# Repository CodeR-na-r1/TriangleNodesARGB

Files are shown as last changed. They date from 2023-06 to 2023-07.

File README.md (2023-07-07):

# Проект по летней практике 2023

## О проекте

Этот проект - моя попытка сделать многофункциональный модульный светильник с ноля за 20 дней. Задач было много: от разработки концепта и корпуса для светильника до написания кода на с++ arduino для реализации функционала. Написание кода оказалось не простой задачей, так как заставить микроконтроллеры коммуницировать между собой с условием, что в run-time может меняться конфигурация системы, довольно сложно.

Результаты можно посмотреть в этом видео -> https://youtu.be/zxDmPbXJ-Gc

## Как запустить проект

Установаить поддержку для esp8266 в Arduino IDE, добавить нужные библиотеки (инструкция ниже) и загрузить прошивку на МК.

## Модули, библиотеки (список, способ установки)

+ Wi-Fi: Работа с подключением к сетям Wi-Fi, а также создание собственной точки доступа Wi-Fi (by default)
+ FastLED: Удобная работа с адресной светодиодной лентой (FastLED by Daniel Garcia)
+ Ticker: Работа с прерываниями по таймеру (by default)
+ ESPAsyncWebSrv: Запуск веб-сервера на микроконтроллере (ESPAsyncWebSrv by dvarrel) (https://github.com/dvarrel/ESPAsyncWebSrv)

Библиотеки либо уже установлены в Arduino IDE (те, что с меткой *by default*), либо устанавливаются через менеджер библиотек

## Основные компоненты:

1. Плата мк esp8266
2. Адресная светодиодная лента, плотность не менее 60 светодиодов на метр, длина 12-24 светодиода
3. Макетная плата для размещения компонентов (при помощи пайки)

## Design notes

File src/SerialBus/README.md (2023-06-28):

Библиотека для объединения микроконтроллеров в единую сеть с общей шиной при помощи интерфейса UART (SoftwareSerial).

В конструкторе необходимо настроить нужный размер буффера, так как библиотека пока что не защищена от его переполнения.

Преимущества:
+ Возможность динамической адресации (по сравнению с i2c или spi). Во время выполнения, мк имеет возможность поменять свой адрес.
    > Каждому отправляемому сообщению можно назначить адрес, либо отправить сообщение для всех (широковещательная рассылка)
+ Высокая скорость передачи данных по сравнению с другими топологиями сети, например кольцевая шина
+ Высокая надежность
    > Встроенная проверка crc при получении сообщения, а также возможность отправлять сообщения, на которые получатель обязательно должен ответить

Ограничения работы:
+ В системе может быть только один мастер. (Но можно адаптировать под нескольких)
+ Все платы slave слышат только мастера, и общаются только с мастером. Они не видят друг друга.
+ Мастер слышит всех и вещает всем.
+ Нельзя допускать, чтобы одновременно более 1 slave говорили что-то мастеру. (это должно контролироваться мастером, например, выдавать квант каждому slave поочереди ИЛИ slave имеет право голоса только если его спросили)

Схема соединения следующая:

> Fake - любой незанятый цифровой пин. Используется библиотекой для работы с Serial.

Гибкая настройка буффера:
+ Задать размер __максимального размера сообщения__ можно прямо в конструкторе класса библиотеки (SerialBusMaster или SerialBusSlave). Имя параметра - _bufferSize_
+ Задать __размер очереди поступаемых сообщений__ - это настраивается через определение директивы препроцессора для библиотеки SoftwareSerial. (Подробнее тут: https://forum.arduino.cc/t/increasing-arduino-serial-buffer-size/322151/19)
    > Вкратце: перед подключением заголовочных файлов SerialBus и SoftwareSerial определить нужную директиву из этих двух (либо две сразу):
    _#define SERIAL_TX_BUFFER_SIZE 128_
    _#define SERIAL_RX_BUFFER_SIZE 128_

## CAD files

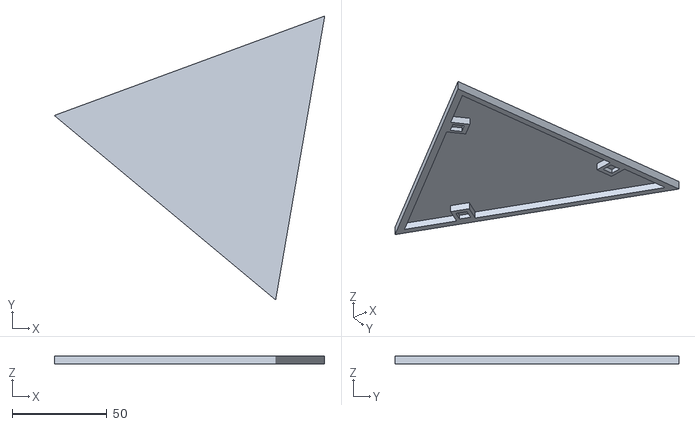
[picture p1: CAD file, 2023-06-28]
3D objects/Node/TreeNode_cap.stl
143.1 x 150.2 x 4.40

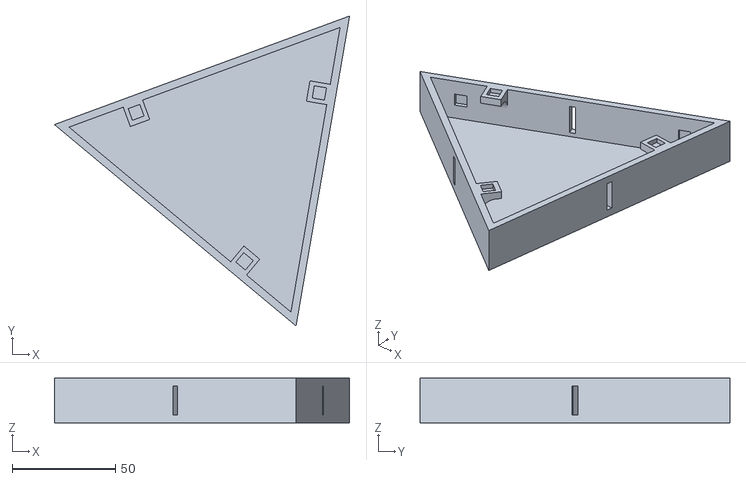
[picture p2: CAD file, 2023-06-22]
3D objects/Node/TreeNode_base.stl
143.1 x 150.2 x 21.6

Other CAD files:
3D objects/Node/TreeNode v1 aka 1.1.f3d
3D objects/Node/TreeNode v1 aka 1.2.f3d
3D objects/Node/TreeNode v1 aka 1.f3d

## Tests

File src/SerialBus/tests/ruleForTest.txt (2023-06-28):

Алгоритм проведения теста:
1. Прошить платы (master + slave). Дождаться.
2. Отключить master
3. Перезагрузить slave
4. Открыть монитор порта для нужных плат (у мастера больше всего инфы)
5. Подключить master

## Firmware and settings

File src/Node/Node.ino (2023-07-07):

#include <Ticker.h>  //Ticker Library

// #define DEBUG_

#include "SerialBusSlave.h"
#include "MSG_TYPES.h"
#include "ARGB_MODES.h"
#include "LedManager.h"

#define MSG_TIME_WAIT 300
#define MSG_SEND_INTERVAL 200
const uint32_t MULTIPLIER_TIMEOUT_PING = 5000;
uint32_t TIMEOUT_PING = MULTIPLIER_TIMEOUT_PING * 1;

#define RX_PIN 4     // D2
#define TX_PIN 0     // D3
#define FAKE_PIN 16  // D0

#define WDP_PIN 2    // D4
#define WDC0_PIN 12  // D6 (right neigbour)
#define WDC1_PIN 14  // D5 (down neigbour)

#define LED_PIN 5  // D1
#define LED_NUM 12

SerialBusSlave bus = SerialBusSlave(RX_PIN, TX_PIN, FAKE_PIN, BROADCAST_ADDR, 100);  // RX 2 TX 3 Fake 0 addr 0 bufSz 100
char* buffer = new char[100];

// void (*animationFunction)() = nullptr;

Ticker ticker;

bool addrSuccess = false;
auto timerPingResponse = millis();
auto timerLastPing = millis();

ColorRGB color = ColorRGB(59, 26, 93);
ColorRGB colorBackground = ColorRGB(0, 0, 0);
ARGB_MODES mode = ARGB_MODES::STATIC_COLOR;
uint8_t timeDelayAnimation = 60;

void setup() {
  Serial.begin(9600);
  Serial.println("ESP started");

  LED_MANAGER::setUp();

  pinMode(WDP_PIN, INPUT_PULLUP);
  pinMode(WDC0_PIN, OUTPUT);
  pinMode(WDC1_PIN, OUTPUT);

  digitalWrite(WDC0_PIN, HIGH);
  digitalWrite(WDC1_PIN, HIGH);

  // SET LOADING STATIC COLOR
  LED_MANAGER::setBrightness(80);
  color = ColorRGB(255, 255, 255);
  reInitAnimation();

  while (true) {  // дальше не идем пока не получим адрес

    if (isPing()) {  // если нас опрашивают

      if (getAddr()) {  // пробуем получить адрес

        addrSuccess = true;
        // TODO SET RAINBOW ANIMATION
        break;
      }
    } else {
      bus.clearBuffer();  // пока мы ждем,
                          // возможно сейчас присвают адрес другим slave при помощи широковещательного сообщения - нам это не нужно,
                          // поэтому чистим буфер
    }
  }

  Serial.println("ESP ready");
  Serial.print("Addr =");
  Serial.println(bus.getAddress());

  LED_MANAGER::setBrightness(255);
  mode = ARGB_MODES::ANIMATION;
  color = ColorRGB(23, 8, 59);
  LED_MANAGER::initLoadAnimation(color, colorBackground, 0, 3, 1);
  timeDelayAnimation = 240;
  reInitAnimation();

  timerPingResponse = millis();
  timerLastPing = millis();
}

void loop() {

  if (bus.available()) {

    char cmd = bus.getData()[0];

    switch (cmd) {

      case static_cast<char>(MSG_TYPES::PING):
        buffer[0] = static_cast<char>(MSG_TYPES::PONG);
        bus.send(1, buffer, 1);
        break;

      case static_cast<char>(MSG_TYPES::SET_TIMEOUT_PING):
        TIMEOUT_PING = MULTIPLIER_TIMEOUT_PING * bus.getData()[1];
        timerLastPing = millis();
        break;

      case static_cast<char>(MSG_TYPES::SET_WD_0):
        digitalWrite(WDC0_PIN, LOW);
        break;

      case static_cast<char>(MSG_TYPES::SET_WD_1):
        digitalWrite(WDC1_PIN, LOW);
        break;

      case static_cast<char>(MSG_TYPES::RESET_WDs):
        digitalWrite(WDC0_PIN, HIGH);
        digitalWrite(WDC1_PIN, HIGH);
        break;

      case static_cast<char>(MSG_TYPES::BRIGHTNESS):
        LED_MANAGER::setBrightness(bus.getData()[1]);
        reInitAnimation();
        break;

      case static_cast<char>(MSG_TYPES::DELAY):
        timeDelayAnimation = bus.getData()[1];
        reInitAnimation();
        break;

      case static_cast<char>(MSG_TYPES::LED_COLOR_INFO):
        color = ColorRGB(bus.getData()[1], bus.getData()[2], bus.getData()[3]);
        reInitAnimation();
        break;

      case static_cast<char>(MSG_TYPES::LED_MODE_INFO):
        mode = static_cast<ARGB_MODES>(bus.getData()[1]);
        reInitAnimation();
        break;
    }

    Serial.print("getRXaddress=");
    Serial.println(bus.getRXaddress());
    Serial.print("getAddress=");
    Serial.println(bus.getAddress());
    if (bus.getRXaddress() == bus.getAddress()) {
      Serial.print("update timerLastPing");
      timerLastPing = millis();
    }
  }

  if ((millis() - timerLastPing > TIMEOUT_PING) && addrSuccess) {

    addrSuccess = false;
    Serial.print("Addr lost!");
    // TODO SET RECONECT ANIMATION
    LED_MANAGER::initLoadAnimation(ColorRGB(255, 0, 0), ColorRGB(0, 0, 0), 0, 3, 1);
    mode = ARGB_MODES::ANIMATION;
    timeDelayAnimation = 80;
    reInitAnimation();
  }

  if (isPing()) {

    if (addrSuccess) {

      if (millis() - timerPingResponse > MSG_SEND_INTERVAL) {

        buffer[0] = static_cast<char>(MSG_TYPES::OK);
        bus.send(1, buffer, 1);
        timerPingResponse = millis();
      }
    } else {

      if (millis() - timerPingResponse > MSG_SEND_INTERVAL) {

        if (getAddr()) {  // пробуем получить адрес

          addrSuccess = true;
          Serial.print("Addr restored!");
          // SET DEFAULT ANIMATION
          mode = ARGB_MODES::ANIMATION;
          LED_MANAGER::initLoadAnimation(color, colorBackground, 0, 3, 1);
          timeDelayAnimation = 240;
          reInitAnimation();
        }
        timerPingResponse = millis();
      }
    }
  }
}

bool waitMessage() {
  auto timer = millis();

  while (millis() - timer < MSG_TIME_WAIT) {
    if (bus.available()) {
      break;
    }
  }

  return bus.available();
}

bool isPing() {

  if (!digitalRead(WDP_PIN)) {  // если нас опрашивают

    // Serial.println("WDP is active");

    auto timer = millis();
    bool flagSuccessful = false;

    while (!digitalRead(WDP_PIN)) {  // проверяем некоторое время, что сигнал не пропал (защита от помех)

      if (millis() - timer > 20) {

        flagSuccessful = true;
        break;
      }
      delay(1);
    }

    return flagSuccessful;
  }

  return false;
}

bool getAddr() {

  Serial.println("Try get addr -> send broadcast");

  bus.clearBuffer();

  buffer[0] = static_cast<char>(MSG_TYPES::GET_ADDR);  // говорим что нам нужен адрес
  bus.send(1, buffer, 1);

  if (!waitMessage()) {  // не дождались ответа
    Serial.println("!ERROR Try get addr -> no msg");
    return false;
  }

  if (bus.getData()[0] != static_cast<char>(MSG_TYPES::SET_ADDR)) {  // не тот тип ответа
    Serial.println("!ERROR Try get addr -> miss type msg (!= ::SET_ADDR)");
    return false;
  }

  uint8_t newAddr = bus.getData()[1];  // если до сюда дошли, значит мы получили адрес
  bus.changeAddress(newAddr);          // меняем свой адрес

  buffer[0] = static_cast<char>(MSG_TYPES::PONG);  // отмечаемся
  bus.send(1, buffer, 1);

  return true;
}

void reInitAnimation() {

  ticker.detach();

  if (mode == ARGB_MODES::STATIC_COLOR) {

    LED_MANAGER::showColor(color);

  } else if (mode == ARGB_MODES::STATIC_COLOR_ANIM) {

    LED_MANAGER::ledFunction = LED_MANAGER::tickStaticColor;

    // if (timeDelayAnimation < 100) { timeDelayAnimation = 270; }  // remove it if user setting delay in web-interface
    ticker.attach_ms(timeDelayAnimation, interruptFunction);

  } else if (mode == ARGB_MODES::ANIMATION) {

    LED_MANAGER::ledFunction = LED_MANAGER::tickAnimation;
    ticker.attach_ms(timeDelayAnimation, interruptFunction);

  } else if (mode == ARGB_MODES::RAINBOW_ANIM) {

    LED_MANAGER::ledFunction = LED_MANAGER::rainbow_fade;
    // timeDelayAnimation = 20;
    ticker.attach_ms(timeDelayAnimation, interruptFunction);

  } else if (mode == ARGB_MODES::COLOR_BOUNCE_FADE) {

    LED_MANAGER::ledFunction = LED_MANAGER::color_bounceFADE;
    // timeDelayAnimation = 20;
    ticker.attach_ms(timeDelayAnimation, interruptFunction);
  }
}

IRAM_ATTR void interruptFunction() {

  LED_MANAGER::ledFunction();
}

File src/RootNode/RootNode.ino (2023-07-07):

#include <SoftwareSerial.h>

// #define DEBUG_

#include "SerialBusMaster.h"
#include "MSG_TYPES.h"
#include "ServerModule.h"
#include "ARGB_MODES.h"

#define MSG_TIME_WAIT 250
#define PING_PONG_FREQUENCY 850

#define RX_PIN 4  // D2
#define TX_PIN 0  // D3

SoftwareSerial mySerial(RX_PIN, TX_PIN);  // RX, TX (2, 3)

#define WD_PIN 5  // D1

SerialBusMaster bus(&mySerial, 1, 100);
char* buffer = nullptr;

std::vector<uint8_t> nodes;
uint8_t freeAddr = 2;

auto timerPingPong = millis();

/* address strip parameters */

char brightness = 255;
char ledDelay = 240;
char mode = static_cast<char>(ARGB_MODES::ANIMATION);
char rColor = 23;
char gColor = 8;
char bColor = 59;

char* queueBuffer = new char[20];
uint8_t queueSize = 0;
bool isQueueData = false;

void setup() {
  Serial.begin(9600);
  mySerial.begin(9600);
  Serial.println("ESP started");

  if (WIFI_AP_NAMESPACE::start() == 0) {
    Serial.println("WIFI AP created");
  } else {
    Serial.println("Wifi AP created error!");
  }

  int ret = SERVER_NAMESPACE::start();

  if (ret == 0) {
    Serial.println("Server started;");

    SERVER_NAMESPACE::setuserCahngeColorCallback(serverChangeColorCallback);
    SERVER_NAMESPACE::setuserCahngeBrightnessCallback(serverChangeBrightnessCallback);
    SERVER_NAMESPACE::setuserCahngeDelayCallback(serverChangeDelayCallback);
    SERVER_NAMESPACE::setuserCahngeModeCallback(serverChangeModeCallback);
    Serial.println("setUserCallback is set");
  } else {
    Serial.print("Server started, with error, retValue -> ");
    Serial.println(ret);
  }

  buffer = new char[100];

  nodes.reserve(10);

  pinMode(WD_PIN, OUTPUT);

  digitalWrite(WD_PIN, LOW);

  while (true) {  // дальше не идем пока не подключимся к 1 ноде

    if (waitMessage()) {  // получили ответ от ноды

      Serial.println("msg get");
      if (assignAddress()) {  // попытка дать адрес

        digitalWrite(WD_PIN, HIGH);
        break;  // успешно - выходим
      }
    }
  }
  Serial.println("first node find");

  timerPingPong = millis();
}

uint8_t nodeIterator = 0;
bool isSecondNeigbour = false;

void loop() {

  if (millis() - timerPingPong > PING_PONG_FREQUENCY) {

    bus.clearBuffer();

    buffer[0] = static_cast<char>(MSG_TYPES::PING);
    bus.send(nodes[nodeIterator], buffer, 1);

    if (waitMessage()) {

      if (bus.getData()[0] == static_cast<char>(MSG_TYPES::PONG)) {

        buffer[0] = static_cast<char>(isSecondNeigbour == false ? MSG_TYPES::SET_WD_0 : MSG_TYPES::SET_WD_1);
        bus.send(nodes[nodeIterator], buffer, 1);

        if (waitMessage()) {  // получили ответ от ноды (либо у которой есть адрес, либо нету)

          Serial.print("after pong (response OK (0) or GET_ADDR(1))\naddr  node intent = ");
          Serial.println(nodes[nodeIterator]);
          Serial.print("isSecondNeigbour = ");
          Serial.println(isSecondNeigbour);
          Serial.print("TYPE_MSG  = ");
          Serial.println(static_cast<int>(bus.getData()[0]));

          if (bus.getData()[0] == static_cast<char>(MSG_TYPES::GET_ADDR)) {  // (которая отреагировала на watch dog (то есть безАдресная))

            if (assignAddress()) {  // попытка дать адрес

              buffer[0] = static_cast<char>(MSG_TYPES::SET_TIMEOUT_PING);
              buffer[1] = nodes.size() & 0xFF;
              bus.sendBroadcast(buffer, 2);

              // send state new node

              sendState(nodes[nodes.size() - 1]);
            }
          }
        }

        buffer[0] = static_cast<char>(MSG_TYPES::RESET_WDs);
        bus.send(nodes[nodeIterator], buffer, 1);
      }
    } else {

      Serial.print("Erase node, addres -> ");
      Serial.println(nodes[nodeIterator]);
      Serial.print("; remains -> ");
      nodes.erase(nodes.begin() + nodeIterator);
      Serial.println(nodes.size());

      Serial.println("nodes = ");
      for (int i = 0; i < nodes.size(); ++i) {
        if (i > 0) { Serial.print(", "); }
        Serial.print(nodes[i]);
      }
      Serial.println();

      if (nodes.size() == 0) {
        Serial.println("Nodes nothing. EPS reset!");
        ESP.reset();
      }

      buffer[0] = static_cast<char>(MSG_TYPES::SET_TIMEOUT_PING);
      buffer[1] = nodes.size() & 0xFF;
      bus.sendBroadcast(buffer, 2);

      nodeIterator = nodeIterator % nodes.size();
      Serial.print("nodeIterator = ");
      Serial.println(nodeIterator);
      isSecondNeigbour = false;
    }

    if (isSecondNeigbour == false) {
      isSecondNeigbour = true;
    } else {
      isSecondNeigbour = false;
      ++nodeIterator;
      if (nodeIterator >= nodes.size()) { nodeIterator = 0; }
    }

    timerPingPong = millis();
  }

  // handler for queue msgs from serverCallback or microPhone and others

  if (isQueueData) {

    bus.sendBroadcast(queueBuffer, queueSize);
    isQueueData = false;
  }
}

bool waitMessage() {
  auto timer = millis();

  while (millis() - timer < MSG_TIME_WAIT) {
    if (bus.available()) {
      break;
    }
  }

  return bus.available();
}

bool assignAddress() {
  Serial.println("assignAddress");
  if (bus.getData()[0] == static_cast<char>(MSG_TYPES::GET_ADDR)) {
    buffer[0] = static_cast<char>(MSG_TYPES::SET_ADDR);
    buffer[1] = freeAddr;
    bus.send(BROADCAST_ADDR, buffer, 2);
    Serial.println("sendAddr");
    if (!waitMessage()) { return false; }
    if (bus.getData()[0] == static_cast<char>(MSG_TYPES::PONG) && bus.getTXaddress() == freeAddr) {
      Serial.print("Add new node with address -> ");
      Serial.println(freeAddr);
      nodes.push_back(freeAddr++);
      return true;
    }
  }

  return false;
}

void serverChangeColorCallback(String _r, String _g, String _b) {

  queueBuffer[0] = static_cast<char>(MSG_TYPES::LED_COLOR_INFO);
  queueBuffer[1] = atoi(_r.c_str());
  queueBuffer[2] = atoi(_g.c_str());
  queueBuffer[3] = atoi(_b.c_str());

  isQueueData = true;

  queueSize = 4;

  // save state

  rColor = atoi(_r.c_str());
  gColor = atoi(_g.c_str());
  bColor = atoi(_b.c_str());

  Serial.print("r = ");
  Serial.println(_r);

  Serial.print("g = ");
  Serial.println(_g);

  Serial.print("b = ");
  Serial.println(_b);
}

void serverChangeBrightnessCallback(String _brightness) {

  queueBuffer[0] = static_cast<char>(MSG_TYPES::BRIGHTNESS);
  queueBuffer[1] = atoi(_brightness.c_str());

  isQueueData = true;

  queueSize = 2;

  brightness = atoi(_brightness.c_str());

  Serial.print("brightness = ");
  Serial.println(_brightness);
}

void serverChangeDelayCallback(String _delay) {

  queueBuffer[0] = static_cast<char>(MSG_TYPES::DELAY);
  queueBuffer[1] = atoi(_delay.c_str());

  isQueueData = true;

  queueSize = 2;

  ledDelay = atoi(_delay.c_str());

  Serial.print("delay = ");
  Serial.println(_delay);
}
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

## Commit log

2023-06-20 create repository, acreate 3d model for TriagnleNode base
    [TreeNode v9 aka 1.1.f3d, TreeNode v9 aka 1.f3d, TreeNode.stl]
2023-06-22 add tests for 2 boards [no stable]
2023-06-22 add send with commiting, add tests for3 boards
2023-06-22 update model node_base
    [TreeNode v9 aka 1.1.f3d, TreeNode.stl]
2023-06-28 create cap 3d model for node
    [TreeNode v1 aka 1.1.f3d, TreeNode v1 aka 1.2.f3d, TreeNode v1 aka 1.f3d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]
2023-07-05 report ready, code fix
    [LedManager.h, Node.ino]
2023-07-06 integrate led modes in sketches
